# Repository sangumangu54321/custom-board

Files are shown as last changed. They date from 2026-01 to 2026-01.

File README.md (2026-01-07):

# CUSTOM-BOARD 
IT IS A DEVLOPMENT BOARD USING ESP32=S3R8 WITH 16MB FLASH 




## feature
• ESP32-S3 series of SoCs embedded, Xtensa®
dual-core 32-bit LX7 microprocessor (with
single precision FPU), up to 240 MHz
• 384 KB ROM
• 512 KB SRAM
• 16 KB SRAM in RTC
• Up to 16 MB PSRAM

## BOM
| Item | Cost  | Note | Suppier |
|---|---|---|---|
| PCB | 14.8  | 4-Layers | https://jlcpcb.com/ |
| PCBA | 99.82 | Kinda Dense board | https://jlcpcb.com/ |
| Shipping from JLC | 14.08 | using the cheapest option avalable | https://jlcpcb.com/ |
| coupon Discount | -6 | SMT monthly coupon | |
| Total | 122.7 | USD | |

# Schematic 


# PCB 
This is 4 layer PCB
## 1st layer 


## 2nd layer 


## 3rd layer 


## 4th layer


## PCB component 

| | | | | | | | | | | | | | | | | | |
|---|---|---|---|---|---|---|---|---|---|---|---|---|---|---|-----|---|---|
| | | | | | | | | | | | | | | | | | |
| | | | | | | | | | | | | | | | | | |
| | | | | | | | | | | | | | | | | | |
| Top Designator | Bottom Designator | Comment | Footprint | JLCPCB Part # | Matches | Part # | Manufacturer | Footprint | Description | Category | Warning | JLCPCB Part # | Product link | Lib Type | Qty | Source | Total Price ($) |
| C2 | | 100nF | C0402 | | Select by System | CL05B104KO5NNNC | Samsung Electro-Mechanics | 0402 | 100nF 16V X7R ±10% 0402 Multilayer Ceramic Capacitors MLCC - SMD/SMT ROHS | Multilayer Ceramic Capacitors MLCC - SMD/SMT | | C1525 | https://jlcpcb.com/partdetail/1877-CL05B104KO5NNNC/C1525 | Basic | 35  | 35 JLCPCB | 0.042 |
| C25,C26,C27,C28 | | 100nF | C0402 | | Select by System | CL05B104KO5NNNC | Samsung Electro-Mechanics | 0402 | 100nF 16V X7R ±10% 0402 Multilayer Ceramic Capacitors MLCC - SMD/SMT ROHS | Multilayer Ceramic Capacitors MLCC - SMD/SMT | | C1525 | https://jlcpcb.com/partdetail/1877-CL05B104KO5NNNC/C1525 | Basic | 35  | 35 JLCPCB | 0.042 |
| C3,C8,C10,C16 | | 10uF | C0402 | | Select by System | CL05A106MP5NUNC | Samsung Electro-Mechanics | 0402 | 10V 10uF X5R ±20% 0402 Multilayer Ceramic Capacitors MLCC - SMD/SMT ROHS | Multilayer Ceramic Capacitors MLCC - SMD/SMT | | C315248 | https://jlcpcb.com/partdetail/297154-CL05A106MP5NUNC/C315248 | Extended | 32  | 32 JLCPCB | 0.2656 |
| C4 | | 1uF | C0603 | | Unconfirmed | CL21B105KBFNNNE | Samsung Electro-Mechanics | 0805 | 1uF 50V X7R ±10% 0805 Multilayer Ceramic Capacitors MLCC - SMD/SMT ROHS | Multilayer Ceramic Capacitors MLCC - SMD/SMT | 1.Multiple lines in the BOM have been matched to the same part. Please check if the matching is correct. ; | C28323 | https://jlcpcb.com/partdetail/29074-CL21B105KBFNNNE/C28323 | Basic | 30  | 30 JLCPCB | 0.273 |
| C19,C20,C30 | | 1uF 50V X7R ±10% 0805 Multilayer Ceramic Capacitors MLCC - SMD/SMT ROHS | C0805 | | Unconfirmed | CL21B105KBFNNNE | Samsung Electro-Mechanics | 0805 | 1uF 50V X7R ±10% 0805 Multilayer Ceramic Capacitors MLCC - SMD/SMT ROHS | Multilayer Ceramic Capacitors MLCC - SMD/SMT | 1.Multiple lines in the BOM have been matched to the same part. Please check if the matching is correct. ; | C28323 | https://jlcpcb.com/partdetail/29074-CL21B105KBFNNNE/C28323 | Basic | 30  | 30 JLCPCB | 0.273 |
| C5,C29 | | 1pF 50V Ceramic Capacitor C0G 0402 | C0402 | | Select by System | GJM1555C1H1R0BB01D | Murata Electronics | 0402 | 1pF 50V C0G 0402 Multilayer Ceramic Capacitors MLCC - SMD/SMT ROHS | Multilayer Ceramic Capacitors MLCC - SMD/SMT | | C76898 | https://jlcpcb.com/partdetail/MurataElectronics-GJM1555C1H1R0BB01D/C76898 | Extended | 20  | 20 JLCPCB | 0.23 |
| C6,C9 | | 10pF | C0603 | | Select by System | CL10C100JB8NNNC | Samsung Electro-Mechanics | 0603 | 10pF 50V C0G ±5% 0603 Multilayer Ceramic Capacitors MLCC - SMD/SMT ROHS | Multilayer Ceramic Capacitors MLCC - SMD/SMT | | C1634 | https://jlcpcb.com/partdetail/1986-CL10C100JB8NNNC/C1634 | Basic | 20  | 20 JLCPCB | 0.09 |
| C7 | | 22uF | C1206 | | Select by System | CL31A226KAHNNNE | Samsung Electro-Mechanics | 1206 | 22uF 25V X5R ±10% 1206 Multilayer Ceramic Capacitors MLCC - SMD/SMT ROHS | Multilayer Ceramic Capacitors MLCC - SMD/SMT | | C12891 | https://jlcpcb.com/partdetail/13537-CL31A226KAHNNNE/C12891 | Basic | 9 | 9 JLCPCB  | 0.3663 |
| C14 | | 1uF | C0603 | | Select by System | CL10A105KB8NNNC | Samsung Electro-Mechanics | 0603 | 1uF 50V X5R ±10% 0603 Multilayer Ceramic Capacitors MLCC - SMD/SMT ROHS | Multilayer Ceramic Capacitors MLCC - SMD/SMT | | C15849 | https://jlcpcb.com/partdetail/16531-CL10A105KB8NNNC/C15849 | Basic | 20  | 20 JLCPCB | 0.096 |
| D1 | | HPESD5V0U1BA-Q | SOD-323_L1.7-W1.3-LS2.5-BI | | Select by System | HPESD5V0U1BA-Q | HXY MOSFET | SOD-323 | -40℃~+125℃ 1 12.9V 1uA 2.5pF 2A 30W@8/20us 5.4V 5V Bidirectional ESD IEC 61000-4-2 SOD-323 ESD and Surge Protection (TVS/ESD) ROHS | ESD And Surge Protection (TVS/ESD) | | C25503782 | https://jlcpcb.com/partdetail/HXYMOSFET-HPESD5V0U1BAQ/C25503782 | Extended | 11  | 11 JLCPCB | 0.2497 |
| D4,D5 | | SS14L | SOD-123F_L2.8-W1.8-LS3.7-RD | | Select by System | SS14L | Guangdong Hottech | SOD-123FL | 1A 30A 40V 500uA@40V 550mV@1A SOD-123FL Schottky Diodes ROHS | Schottky Diodes | | C190475 | https://jlcpcb.com/partdetail/GuangdongHottech-SS14L/C190475 | Extended | 20  | 20 JLCPCB | 0.272 |
| JP1 | | 6GHz | RF-SMD_FRF05002-JSS103M | | Select by System | U.FL-R-SMT-1(80) | HRS(Hirose) | SMD | -40℃~+90℃ 1 1.25mm 2mm 50Ω 6GHz Board Side IPEX Male Pin SMD Coaxial Connectors (RF) ROHS | Coaxial Connectors (RF) | | C88374 | https://jlcpcb.com/partdetail/HRS_Hirose-U_FL_R_SMT_1_80/C88374 | Extended | 7 | 7 JLCPCB  | 0.8386 |
| L1,L2 | | 2.0nH | L0603 | | Select by System | LQG15HS2N0S02D | Murata Electronics | 0402 | 2nH 6GHz 8@100MHz 900mA 90mΩ 0402 Inductors (SMD) ROHS | Inductors (SMD) | | C18216 | https://jlcpcb.com/partdetail/MurataElectronics-LQG15HS2N0S02D/C18216 | Extended | 22  | 22 JLCPCB | 0.1716 |
| LED1 | | XL-1608SURC-06 | LED0603-RD_RED | | Select by System | XL-1608SURC-06 | XINGLIGHT | 0603 | -40℃~+85℃ 120° 2.3V 20mA 225mcd 50mW 620nm~630nm 625nm Red Top-mount Water Clear 0603 LED Indication - Discrete ROHS | LED Indication - Discrete | | C965799 | https://jlcpcb.com/partdetail/XINGLIGHT-XL_1608SURC06/C965799 | Extended | 20  | 20 JLCPCB | 0.06 |
| LED2,LED4 | | XL-1608UBC-04 | LED0603-RD_BLUE | | Select by System | XL-1608UBC-04 | XINGLIGHT | 0603 | 120° 20mA 3.3V 300mcd 455nm~475nm 470nm 70mW Blue Top-mount Water Clear 0603 LED Indication - Discrete ROHS | LED Indication - Discrete | | C965807 | https://jlcpcb.com/partdetail/XINGLIGHT-XL_1608UBC04/C965807 | Extended | 22  | 22 JLCPCB | 0.077 |
| LED3 | | XL-5050RGBC-2812B | LED-SMD_4P-L5.0-W5.0-BL_XL-5050RGBC | | Select by System | XL-5050RGBC-2812B | XINGLIGHT | SMD5050-4P | -20℃~+85℃ 0.3mA 1.6mm 120° 2000V 3.5V~5.5V 4kHz 5mm 5mm 800Kbit/s G:1300mcd~1800mcd R:620nm~635nm Top-mount Water Clear SMD5050-4P RGB LEDs(Built-in IC) ROHS  | RGB LEDs(Built-In IC) | | C2843785 | https://jlcpcb.com/partdetail/XINGLIGHT-XL_5050RGBC2812B/C2843785 | Extended | 9 | 9 JLCPCB  | 0.3924 |
| Q1,Q2 | | SS8050-G | SOT-23-3_L2.9-W1.5-P1.90-LS2.6-BR | | Select by System | SS8050-G | Comchip | SOT-23 | 1 NPN 1.5A 100@10mA,1V 100MHz 100nA 25V 300mW 400mV@50mA,5mA 5V NPN SOT-23 Bipolar (BJT) ROHS | Bipolar (BJT) | | C3199946 | https://jlcpcb.com/partdetail/Comchip-SS8050G/C3199946 | Extended | 10  | 10 JLCPCB | 0.629 |
| R8 | | 499 | R0603 | | Select by System | RC0402FR-07499RL | YAGEO | 0402 | -55℃~+155℃ 499Ω 50V 62.5mW Thick Film Resistor ±1% ±100ppm/℃ 0402 Chip Resistor - Surface Mount ROHS | Chip Resistor - Surface Mount | | C137970 | https://jlcpcb.com/partdetail/YAGEO-RC0402FR07499RL/C137970 | Extended | 20  | 20 JLCPCB | 0.014 |
| R14 | | 0Ω | R0603 | | Select by System | 0603WAF0000T5E | UNI-ROYAL(Uniroyal Elec) | 0603 | -55℃~+155℃ 0Ω 100mW 75V Thick Film Resistor ±1% 0603 Chip Resistor - Surface Mount ROHS | Chip Resistor - Surface Mount | | C21189 | https://jlcpcb.com/partdetail/21903-0603WAF0000T5E/C21189 | Basic | 20  | 20 JLCPCB | 0.022 |
| R18,R19 | | 10kΩ | R0603 | | Select by System | 0603WAF1002T5E | UNI-ROYAL(Uniroyal Elec) | 0603 | -55℃~+155℃ 100mW 10kΩ 75V Thick Film Resistor ±1% ±100ppm/℃ 0603 Chip Resistor - Surface Mount ROHS | Chip Resistor - Surface Mount | | C25804 | https://jlcpcb.com/partdetail/26547-0603WAF1002T5E/C25804 | Basic | 20  | 20 JLCPCB | 0.022 |
| R23,R24,R25,R26,R27,R28 | | 0Ω | R0402 | | Select by System | RC0402FR-070RL | YAGEO | 0402 | -55℃~+155℃ 0Ω 50V 62.5mW Thick Film Resistor ±1% 0402 Chip Resistor - Surface Mount ROHS | Chip Resistor - Surface Mount | | C106231 | https://jlcpcb.com/partdetail/YAGEO-RC0402FR070RL/C106231 | Extended | 40  | 40 JLCPCB | 0.024 |
| R29,R30,R31,R32 | | 5.1kΩ | R0603 | | Select by System | RC0603FR-075K1L | YAGEO | 0603 | -55℃~+155℃ 100mW 5.1kΩ 75V Thick Film Resistor ±1% ±100ppm/℃ 0603 Chip Resistor - Surface Mount ROHS | Chip Resistor - Surface Mount | | C105580 | https://jlcpcb.com/partdetail/YAGEO-RC0603FR075K1L/C105580 | Extended | 30  | 30 JLCPCB | 0.039 |
| R33,R34 | | 10kΩ | R0603 | | Select by System | RC0603FR-0710KL | YAGEO | 0603 | -55℃~+155℃ 100mW 10kΩ 75V Thick Film Resistor ±1% ±100ppm/℃ 0603 Chip Resistor - Surface Mount ROHS | Chip Resistor - Surface Mount | | C98220 | https://jlcpcb.com/partdetail/YAGEO-RC0603FR0710KL/C98220 | Extended | 20  | 20 JLCPCB | 0.022 |
| R35 | | 2.7kΩ | R0402 | | Select by System | RC0402FR-072K7L | YAGEO | 0402 | -55℃~+155℃ 2.7kΩ 50V 62.5mW Thick Film Resistor ±1% ±100ppm/℃ 0402 Chip Resistor - Surface Mount ROHS | Chip Resistor - Surface Mount | | C138017 | https://jlcpcb.com/partdetail/YAGEO-RC0402FR072K7L/C138017 | Extended | 20  | 20 JLCPCB | 0.014 |
| R36,R37 | | 680Ω | R0402 | | Select by System | RC0402FR-07680RL | YAGEO | 0402 | -55℃~+155℃ 50V 62.5mW 680Ω Thick Film Resistor ±1% ±100ppm/℃ 0402 Chip Resistor - Surface Mount ROHS | Chip Resistor - Surface Mount | | C137948 | https://jlcpcb.com/partdetail/YAGEO-RC0402FR07680RL/C137948 | Extended | 20  | 20 JLCPCB | 0.014 |
| SW1,SW2 | | TS-1088-AR02016 | SW-SMD_L3.9-W3.0-P4.45 | | Select by System | TS-1088-AR02016 | XUNPU | SMD,4x3mm | -30℃~+80℃ 1.6N 100,000 Cycles 12V 2mm 3mm 4mm 50mA Black Round Button SMD(SMT) Tab SPST Surface Mount,Vertical Without Bracket SMD,4x3mm Tactile Switches ROHS | Tactile Switches | | C720477 | https://jlcpcb.com/partdetail/XUNPU-TS_1088AR02016/C720477 | Basic | 14  | 14 JLCPCB | 0.6076 |
| U1 | | ESP32-S3R8 | QFN-56_L7.0-W7.0-P0.40-TL-EP4.0 | | Select by System | ESP32-S3R8 | Espressif Systems | QFN-56(7x7) | -40℃~+65℃ -74.2dBm 150Mbps 18.5dBm 2.412GHz~2.484GHz 2.4GHz 283mA 3V~3.6V 88mA Bluetooth SPI transceiver QFN-56(7x7) RF Transceiver ICs ROHS | RF Transceiver ICs | | C2913194 | https://jlcpcb.com/partdetail/EspressifSystems-ESP32S3R8/C2913194 | Extended | 5 | 5 JLCPCB  | 16.118 |
| U4 | | GD25Q128ESIGR | SOP-8_L5.3-W5.3-P1.27-LS8.0-BL | | Select by System | GD25Q128ESIGR | GigaDevice Semicon Beijing  | SOP-8-208mil | 100,000 Cycles 128Mbit 133MHz 14uA 150ms@(32KB) 2.7V~3.6V 20 Years 500us SPI SOP-8-208mil NOR FLASH ROHS | NOR FLASH | | C2928891 | https://jlcpcb.com/partdetail/3260959-GD25Q128ESIGR/C2928891 | Extended | 5 | 5 JLCPCB  | 6.216 |
| U5,U6 | | TYPEC-ZL-102PWB | TYPE-C-SMD_HDGC_TYPE-C-ZL-103PWB | | Select by System | TYPE C-ZL-102PWB | HDGC | SMD | 1 10,000 cycles 16P 7.35mm Female Surface Mount, Right Angle Type-C maize-yellow SMD USB Connectors ROHS | USB Connectors | | C5273950 | https://jlcpcb.com/partdetail/HDGC-TYPE_C_ZL102PWB/C5273950 | Extended | 10  | 10 JLCPCB | 0.991 |
| U7 | | CH343P | TQFN-16_L3.0-W3.0-P0.50-BL-EP1.7 | | Select by System | CH343P | WCH(Jiangsu Qin Heng) | TQFN-16-EP(3x3) | -40℃~+85℃ 3.3V 3mA 6Mbps 90uA USB 2.0 USB to UART TQFN-16-EP(3x3) USB Converters ROHS | USB Converters | | C2846043 | https://jlcpcb.com/partdetail/WCH_Jiangsu_Qin_Heng-CH343P/C2846043 | Extended | 5 | 5 JLCPCB  | 5.664 |
| U8 | | AMS1117-5.0 | SOT-223_L6.5-W3.5-P2.30-LS7.0-BR | | Select by System | AMS1117-5.0 | Advanced Monolithic Systems | SOT-223 | -40℃~+125℃ 1 1.3V 15V 1A 5V 60dB Fixed Positive SOT-223 Voltage Regulators - Linear, Low Drop Out (LDO) Regulators ROHS | Voltage Regulators - Linear, Low Drop Out (LDO) Regulators | | C6187 | https://jlcpcb.com/partdetail/Advanced_MonolithicSystems-AMS1117_50/C6187 | Basic | 7 | 7 JLCPCB  | 1.3209 |
| X1 | | 40MHz | CRYSTAL-SMD_4P-L3.2-W2.5-BL | | Select by System | XXDBBCNANF-40.000000MHZ | TAITIEN Elec | SMD3225-4P | -20℃~+70℃ 12pF 40MHz Crystal Oscillator ±10ppm ±10ppm SMD3225-4P Crystals ROHS | Crystals | | C521661 | https://jlcpcb.com/partdetail/TAITIENElec-XXDBBCNANF_40000000MHZ/C521661  | Extended | 5 | 5 JLCPCB  | 0.847 |

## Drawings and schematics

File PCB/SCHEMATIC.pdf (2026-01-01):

# FLASH

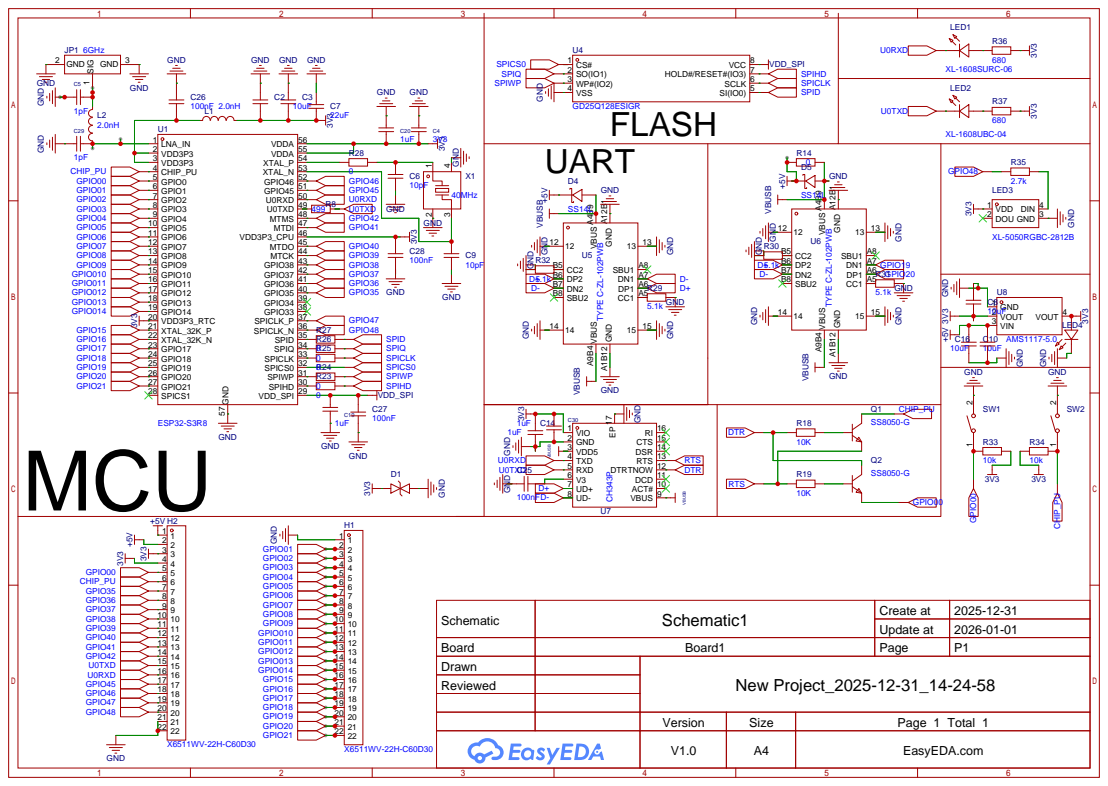
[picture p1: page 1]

GND
ACT# 10 DCD 11 DTRTNOW 12 RTS 13 DSR 14 CTS 15 RI 16 EP ¹⁷

Schematic | Schematic1 | Create at | 2025-12-31

Update at | 2026-01-01

Board | Board1 | Page | P1
Drawn | | New Project_2025-12-31_14-24-58
Reviewed

Version | Size | Page 1 Total 1
V1.0 | A4 | EasyEDA.com

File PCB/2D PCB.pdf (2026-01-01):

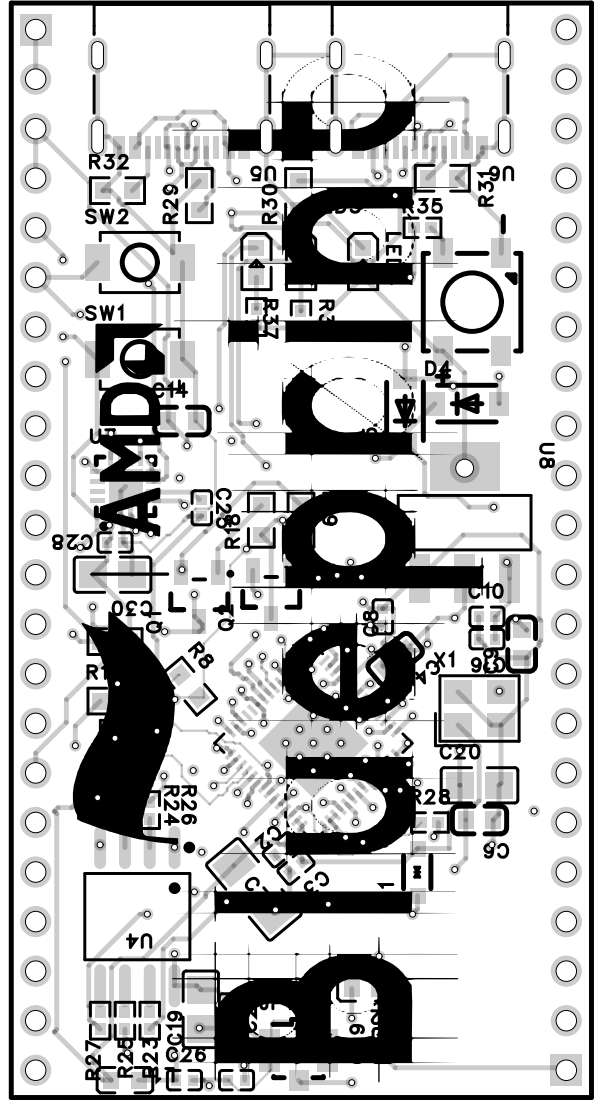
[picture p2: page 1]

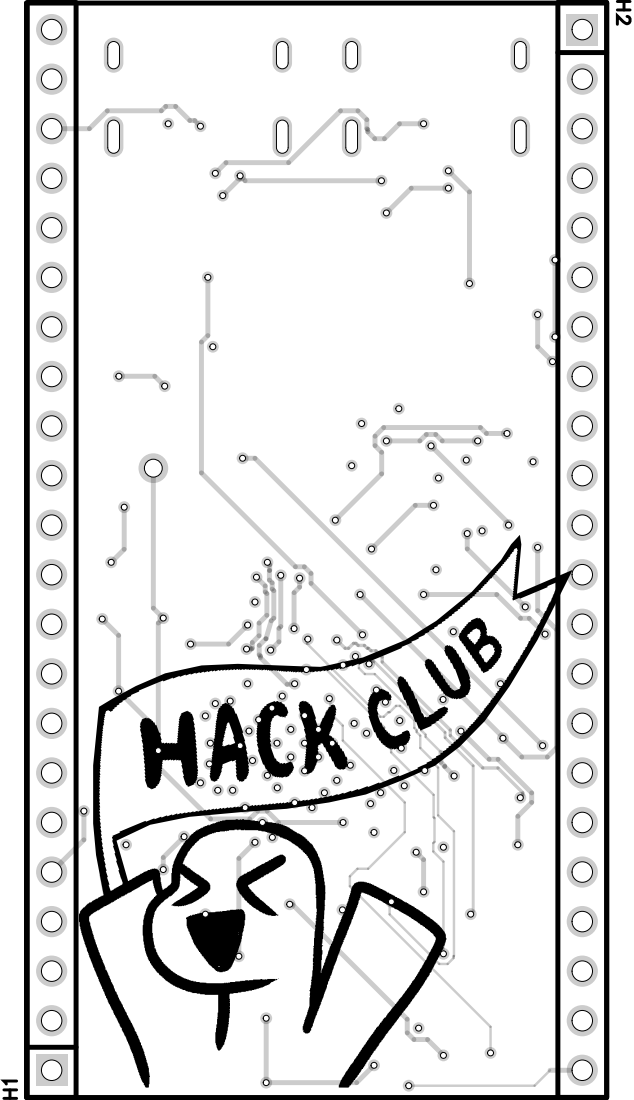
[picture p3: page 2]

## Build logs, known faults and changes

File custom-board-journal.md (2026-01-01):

<!--
  This journal is auto generated by Hack Club Blueprint.
-->

## 12/31/2025 4:21 AM - Selecting the microprocessor   

_Time spent: 0.7h_  

I started with selecting best Microcontroller
there are many MCU avalibable in market 
but i select the ESP32-s3 because there Wide range of communication With Many protocols Including wifi and bLE Which made it a best choice.

For more detail visit https://documentation.espressif.com/esp32-s3-wroom-1_wroom-1u_datasheet_en.pdf  

## 12/31/2025 4:25 AM - best deal  

_Time spent: 0.2h_  

It is easily available on Platforms like LCSC Electronics Which implies it can be easily assembled IN PCBA And second it is Only cost $3 something Which made them very Good MCU


## 12/31/2025 4:52 AM - Start designing Systematic  

_Time spent: 0.6h_  

So after finalising the microcontroller I start preparing I'm systematic
STARTING WITH ESP32-S3R8

USE THE OFFICAL [espressif DOCS](https://documentation.espressif.com/esp32-s3-wroom-1_wroom-1u_datasheet_en.pdf)  

## 12/31/2025 6 AM - MCU CONNECTED   

_Time spent: 2.5h_  

FINALLY AFTER 2.3HOUR WORK THE MCU PINOUT, Timer Crystal CONNECTED AND POWER WIRING DONE 
HERE IS IMAGE TO SHOW WHAT I DONE 

ALL THE MAIN MCU CONNECTION DONE   

## 12/31/2025 10 AM - Flash memory and OTG Port   

_Time spent: 5.0h_  

Hi guys I'm not kidding it's 5 hour work 
I unable to find the Flash memory used in ESP32 Anywhere ON DOCS 
After 2.5 HR I decided to To remove the protective shield from my existing ESP32 Board and see what's there


I Found that it consists of GigaDevice GD25Q128ESIG Flasher Memory 

AND I ADD IT INTO THE Systematic

 and made the connexion and I also added a The diode to protect it FROM Electronic spike And added to usb port One is for OTG and the second one is for Serial communication Otg part is done now I'm working on the serial communication.  

## 12/31/2025 1 PM - Systematic done!  

_Time spent: 3.4h_  

Show after facing many issues I finally completed Systematic of the custom And It really difficult Because Some component Are not disclosed by the official Which I have to find And use it


## 1/1/2026 4 AM - component placement  

_Time spent: 3.8h_  

So finally I completed The component placement And here's the image so you can take a look -


here is board

\
i know this process not take that much time but due to the compact size 
Beginning of my PCB designing it take time

## 1/1/2026 3 PM - routed the pcb   

_Time spent: 6.3h_  

So what I in our previous post I place all the components on the place and he starte route And here's the good news all root is completed. Give a good round of applause to me




## 1/1/2026 4 PM - adding hackclub logo   

_Time spent: 0.4h_  

I added the hackclub logo on the pcb ‎ ‎ ‎ ‎ ‎ ‎ ‎ ‎ ‎ ‎ ‎ ‎ ‎ ‎ ‎ ‎ ‎ ‎ ‎ ‎ ‎ ‎ ‎ ‎ ‎ ‎ ‎ ‎ ‎ ‎ ‎ ‎ ‎ ‎ ‎ ‎ ‎ ‎ ‎ ‎ ‎ ‎ ‎ ‎ ‎ ‎ ‎ ‎ ‎ ‎ ‎ ‎ ‎ ‎ ‎ ‎ ‎ ‎ ‎ ‎ ‎ ‎ ‎ ‎ ‎ ‎ ‎ ‎ ‎


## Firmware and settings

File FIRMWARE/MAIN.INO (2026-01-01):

#include <WiFi.h>
#include <BLEDevice.h>
#include <BLEScan.h>
#include <BLEAdvertisedDevice.h>

#include <Adafruit_NeoPixel.h>



// PIN CONFRIGRATION
#define LED_PIN     48        // RGB NeoPixel pin
#define LED_COUNT   1         // only one LED for test

Adafruit_NeoPixel rgbLed(LED_COUNT, LED_PIN, NEO_GRB + NEO_KHZ800);

BLEScan* pBLEScan;


// VAR
unsigned long lastPrint   = 0;
int scanTime = 5;   // BLE scan time (seconds)



void setup()
{
  Serial.begin(115200);
  delay(500);

  Serial.println();
  Serial.println(" ESP32 TEST STARTING .... ");
  Serial.println(" ------------------------ ");
  Serial.println();



  // ---- RGB LED INIT ----
  rgbLed.begin();
  rgbLed.clear();
  rgbLed.show();

  Serial.println(" NeoPixel Init Done ");
  delay(300);



  // ---- WIFI INIT ----
  WiFi.mode(WIFI_STA);
   WiFi.disconnect();
  delay(100);

  Serial.println(" WiFi set to STA mode ");
  Serial.println();



  // ---- BLE INIT ----
  BLEDevice::init("ESP32_TEST_DEVICE");
  pBLEScan = BLEDevice::getScan();
  pBLEScan->setActiveScan(true);  // better results but more power
  pBLEScan->setInterval(100);
  pBLEScan->setWindow(80);

  Serial.println(" BLE Init Done ");
  Serial.println();



  // random LED color at boot
  rgbLed.setPixelColor(0, rgbLed.Color(20, 0, 20));
  rgbLed.show();

  Serial.println(" Setup Finished .... ");
  Serial.println();
}



void loop()
{
  // ---- SERIAL HEARTBEAT ----
  if (millis() - lastPrint > 3000)
  {
    lastPrint = millis();

    Serial.print(" Uptime (ms): ");
    Serial.print(millis());

    Serial.print(" | Free Heap: ");
    Serial.println(ESP.getFreeHeap());
  }



  // ---- WIFI SCAN ----
  Serial.println();
  Serial.println(" Starting WiFi Scan .... ");

  int n = WiFi.scanNetworks();

  if (n == 0)
  {
    Serial.println(" No WiFi Networks Found ");
    rgbLed.setPixelColor(0, rgbLed.Color(50, 0, 0)); // red
  }
  else
  {
    Serial.print(" WiFi Networks Found: ");
    Serial.println(n);

    rgbLed.setPixelColor(0, rgbLed.Color(0, 50, 0)); // green

    for (int i = 0; i < n; i++)
    {
      Serial.print("  ");
      Serial.print(i + 1);
      Serial.print(" -> ");
      Serial.print(WiFi.SSID(i));
      Serial.print("  RSSI: ");
      Serial.print(WiFi.RSSI(i));
      Serial.print(" dBm ");
      Serial.println();
      delay(10);
    }
  }

  rgbLed.show();
  delay(800);



  // ---- BLE SCAN ----
  Serial.println();
  Serial.println(" Starting BLE Scan .... ");

  BLEScanResults foundDevices = pBLEScan->start(scanTime, false);

  Serial.print(" BLE Devices Found: ");
  Serial.println(foundDevices.getCount());

  pBLEScan->clearResults();   // free memory

  rgbLed.setPixelColor(0, rgbLed.Color(0, 0, 50)); // blue
  rgbLed.show();



  // ---- SMALL DELAY ----
  Serial.println(" Scan Cycle Done .... ");
  Serial.println(" --------------------- ");
  Serial.println();

  delay(4000);   // slow DOWN
}

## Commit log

2026-01-01 CAD ADDED
2026-01-01 PCB ADDED
    [COMPOMONENT_LIST.xls]
